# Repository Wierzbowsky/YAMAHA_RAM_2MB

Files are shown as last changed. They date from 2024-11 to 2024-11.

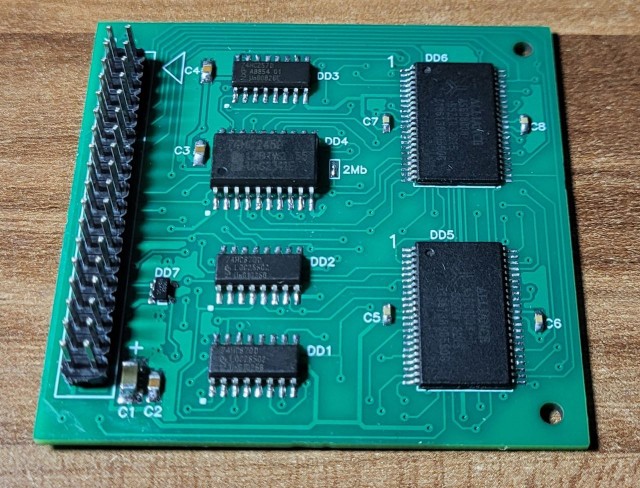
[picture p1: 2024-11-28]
Pics/assembled.jpg

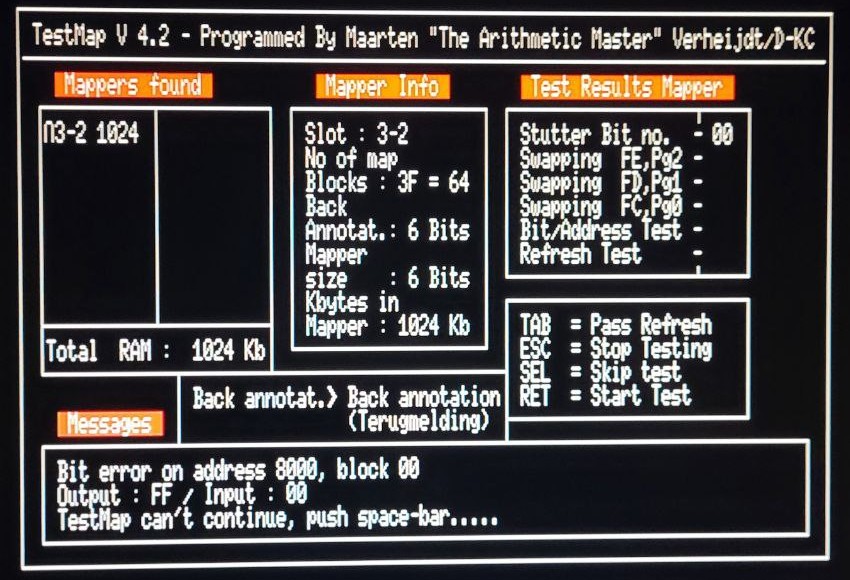
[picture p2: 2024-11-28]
Pics/testmap_error.jpg

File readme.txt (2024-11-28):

Yamaha YIS503 RAM Expansion Board 2MB
-------------------------------------

Designed by Kamil Karimov (k2k@list.ru)
Homepage: http://caro.su/

This reposity contains Gerber files as well as pictures and the schematics for the Yamaha YIS503 2MB RAM
expansion board designed by Kamil Karimov. The board can be used as 1MB or as 2MB RAM expansion in Yamaha MSX2
computers without any modification of the mainboard. To be used in Yamaha MSX1 computers a few additional
components must be installed onto the mainboard to support missing signals.

Mr. Karimov gave his permission to put his files into the repository. However it's not allowed to use any of the
files in this repository for commercial purposes without the permission from the author. Making a small batch of
boards, using some of the boards for personal projects and selling the remaining boards is permitted.

See the partslist.txt file for the information on the necessary components. Replacements are possible for SRAM
chips, as well as small logic component. The cheapest SRAM chip is at the moment AS6C8008-55ZIN.

Please be aware that if only one SRAM chip is installed onto the board, it must be soldered at the DD5 position.
Also, the TESTMAP mapper testing utility may alert (see the "testmap_error.jpg" image) if only one chip is
installed. However, this alert does not mean that the RAM module has a problem - it works properly.

When 2 SRAM chips are installed onto the board, the "2MB" solder jumper on the board must be shorted (see the
"assembled.jpg" image). With 2MB of RAM the TESTMAP utility no longer gives a warning.

It is strongly advised to test the newly-assembled RAM expansion with TESTMAP, TESTRAM and MEMTEST utilities
after installation. There should be no errors beside the one described above (for 1MB configuration).

IMPORTANT!
The commercial usage of this project is not allowed without the permission of the author!

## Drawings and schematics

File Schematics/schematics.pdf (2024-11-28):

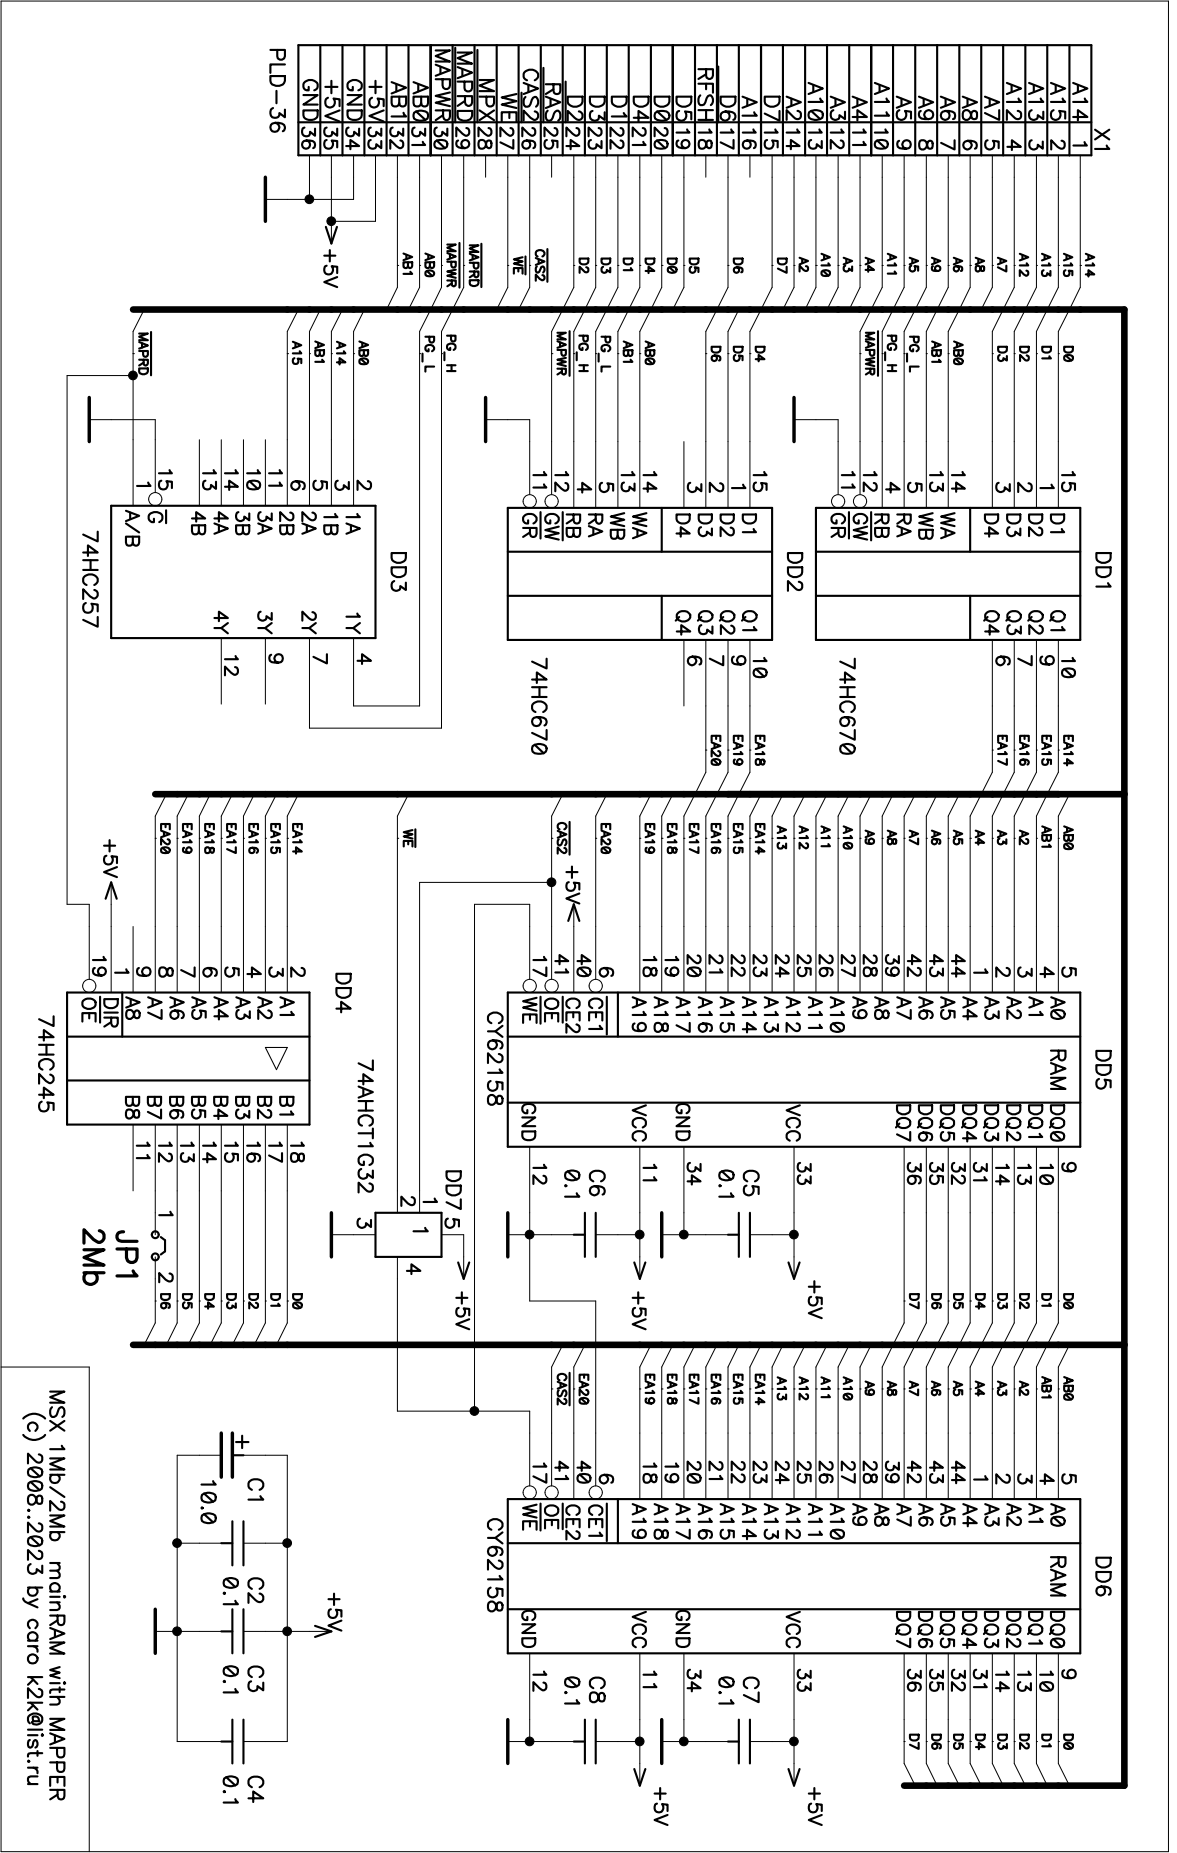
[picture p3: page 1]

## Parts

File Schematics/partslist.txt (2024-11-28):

Partslist
---------

Any of the below mentioned SRAM chips could be used (2 pieces):

CY62158ELL-45ZSXI
Static RAM 8mbit 45ns
Manufacturer: Cypress Semiconductor
Form-factor: TSOP44-II
Type: SRAM - Asynchronous, 8M (1M x 8)
Supported voltages: 4.5 V ~ 5.5 V

IS62C10248AL-55TLI
Static RAM 8mbit 55ns
Manufacturer: Integrated Silicon Solution, Inc
Form-factor: TSOP44-II
Type: SRAM - Asynchronous, 8M (1M x 8)
Supported voltages: 4.5 V ~ 5.5 V

AS6C8008-55ZIN
Static RAM 8mbit 55ns
Manufacturer: Alliance
Form-factor: TSOP44-II
Type: SRAM - Asynchronous, 8M (1M x 8)
Supported voltages: 2.7 V ~ 5.5 V

Other components:

74HC670D SOP16 (2 pieces)
74LS245D SOP24
74HC257D SOP16
74AHCT1G32 SOT23-5 or SN74LVC1G32DBVR SOT23-5
SMD ceramic capacitor 0603 100nF (4 pieces)
SMD ceramic capacitor 0805 100nF (3 pieces)
Tantalum or ceramic capacitor 1206 (or B) 47-100uF 12v

Dual-row pin header 2x18
